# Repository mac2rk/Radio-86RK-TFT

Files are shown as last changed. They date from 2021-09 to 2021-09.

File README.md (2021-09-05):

# Connecting Radio-86RK to TFT display panel

Connecting TFT display with 24bit RGB parallel interface to Intel i8275 CRTC

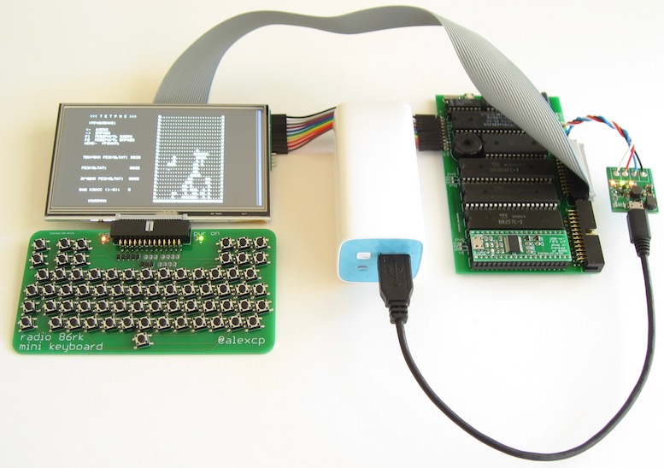
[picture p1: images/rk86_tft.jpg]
Radio-86RK with TFT panel


## Introduction

For many home computers from 1980s, TV was the only display available, and [Radio-86RK](https://github.com/mac2rk/Radio-86RK-SRAM) is no exception. Back then, it made total sense, but today, TVs with composite video input gradualy disappear, and being tethered to one when playing with a 8-bit retro computer is, well, too much retro.

Turns out, small TFT display panels are now available, affordable, and can be connected to Radio-86RK relatively easily.

This project is a hardware interface between Intel i8275 CRT controller and a 480x272 pixel TFT panel [ER-TFT050-2](https://www.buydisplay.com/download/manual/ER-TFT050-2_Datasheet.pdf) with the ILI6482 controller onboard. This inteface board supports 4-bit (IRGB) color, although color is not implemented in [Radio-86RK](https://github.com/mac2rk/Radio-86RK-SRAM). The interface has been shown to work with a Sinclair ZX Spectrum clone (Harlequin), too, although it was not explored in any detail.

## Schematic

[Schematic](Eagle/rk86_tft-schematic.pdf)

In the schematic, IC3 converts logic levels from 5V of [Radio-86RK](https://github.com/mac2rk/Radio-86RK-SRAM) to 3.3V required by the TFT panel; IC6 feeds the TFT panel's backlight (a string of white LEDs) with constant current; IC7 provides I2C interface for the resistive touchscreen; IC8 regulates +5V power supply down to +3.3V. Q1 provides protection against wrong power supply polarity, Q2 and Q3 convert I2C voltage levels.

IC4 and IC5.1 form the brown color `#AA5500`instead of unsightly "dark yellow" `#AAAA00` for IRGB=0b0110, forming the standard CGA palette:

4-bit IRGB code | 24-bit color | Color
--------------- | ------------ | -----
0b0000          | `#000000`    | Black
0b0001          | `#0000AA`    | Blue
0b0010          | `#00AA00`    | Green
0b0011          | `#00AAAA`    | Cyan
0b0100          | `#AA0000`    | Red
0b0101          | `#AA00AA`    | Magenta
0b0110          | `#AA5500`    | Brown
0b0111          | `#AAAAAA`    | Light gray
0b1000          | `#555555`    | Dark gray
0b1001          | `#5555FF`    | Bright blue
0b1010          | `#55FF55`    | Bright green
0b1011          | `#55FFFF`    | Bright cyan
0b1100          | `#FF5555`    | Bright Red
0b1101          | `#FF55FF`    | Bright magenta
0b1110          | `#FFFF55`    | Yellow
0b1111          | `#FFFFFF`    | White

IC2's function is specific to [Radio-86RK](https://github.com/mac2rk/Radio-86RK-SRAM). In Radio-86RK, the i8275 CRTC forms a raster with 300 horizontal lines, although top 30 and bottom 20 are not used for display. The TFT panel, however, is only 272 pixels tall, so 300-20-272=8 lines at the bottom  of the display area do not fit. Thankfully, the TFT panel ignores HRTC pulses and is completely controlled by VRTC and DEN (Data ENable) signals. IC2 suppresses DEN for the top 16 lines, thus fitting the full display area into the panel without reprogramming the CRTC, ensuring compatibility with existing software.

## PCB layout

[PCB layout](Eagle/rk86_tft-board.pdf)

## Bill of Materials

Name              | Part      | Value       | Package | Quantity
----------------- | --------- | ----------- | ------- | --------
LCD1              | LCD panel | ER-TFT050-2 |         | 1
LCD1              | 30-way 0.5mm FPC connector, top contact |  | Molex 54014-4031 | 1
IC1               | Logic IC  | 74HC04PW    | TSSOP14 | 1
IC2               | Logic IC  | 74HC161PW   | TSSOP16 | 1
IC3               | Logic IC  | 74LVC8T245DBQR | TSSOP24 | 1
IC4               | Logic IC  | QS3VH253PAG | TSSOP16 | 1
IC5               | Logic IC  | 74HC08PW    | TSSOP14 | 1
IC6               | Backlight Driver IC | AP3019AKTR | SOT23-6 | 1
IC7               | Touchscreen Controller IC | TSC2007PW | TSSOP16 | 1
IC8               | Voltage Reg IC | MCP1700T-3302E/TT | SOT23-3 | 1
Q1                | Pch MOSFET | FDC658P    | SOT23-6 | 1
Q2,Q3             | Nch MOSFET | BSS138     | SOT23-3 | 2
R1,R2,R4..R7      | Resistor  | 10kOhm | 0805    | 6
R3                | Resistor  | 5ohm   | 0805    | 1
R8..R13           | Resistor  | 220ohm | 0805    | 6
C1..C6, C11, C13  | Capacitor | 0.1uF  | 0805    | 8
C8, C10, C12, C14 | Capacitor | 10uF   | 0805    | 4
C9                | Capacitor | 0.22uF | 0805    | 1
L1                | Inductor | 22uH    | Coilcraft XTL7030 | 1
CLK,DEN,HRTC,I2C,PWR,VRTC | LED |      | 0805    | 6
JP1         | 0.1" Pin Header |        | 1x10    | 1
I2X1        | 0.1" Pin Header |        | 1x4     | 1

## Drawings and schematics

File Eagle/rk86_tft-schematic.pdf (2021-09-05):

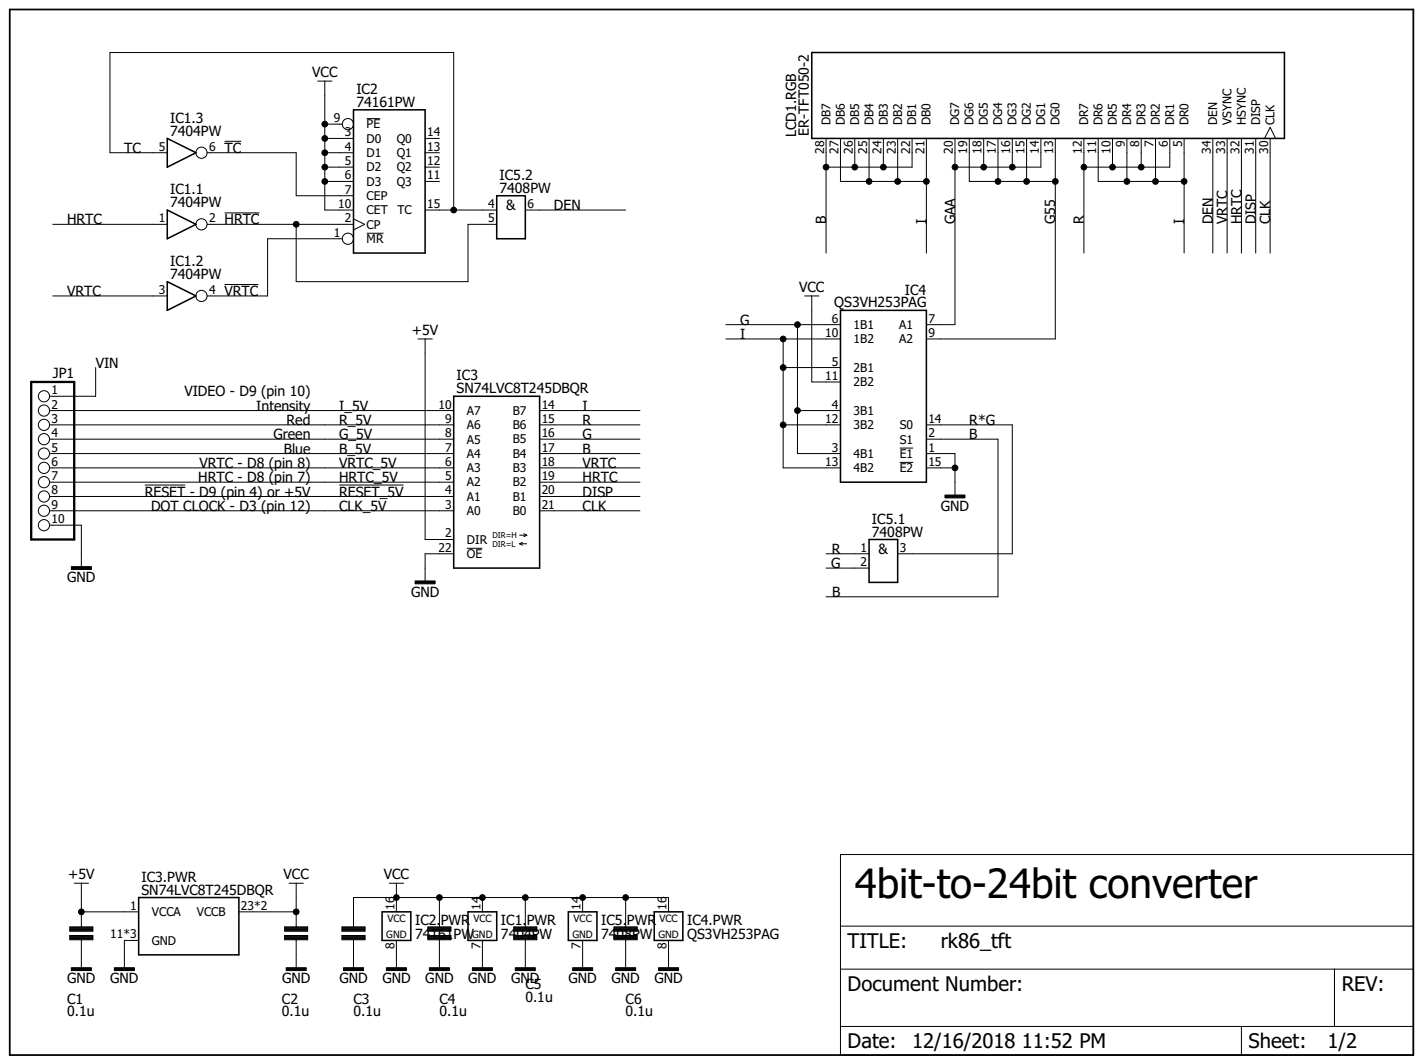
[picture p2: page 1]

VCC

4 | 13
5 | 12
6 | 11
7 | 15

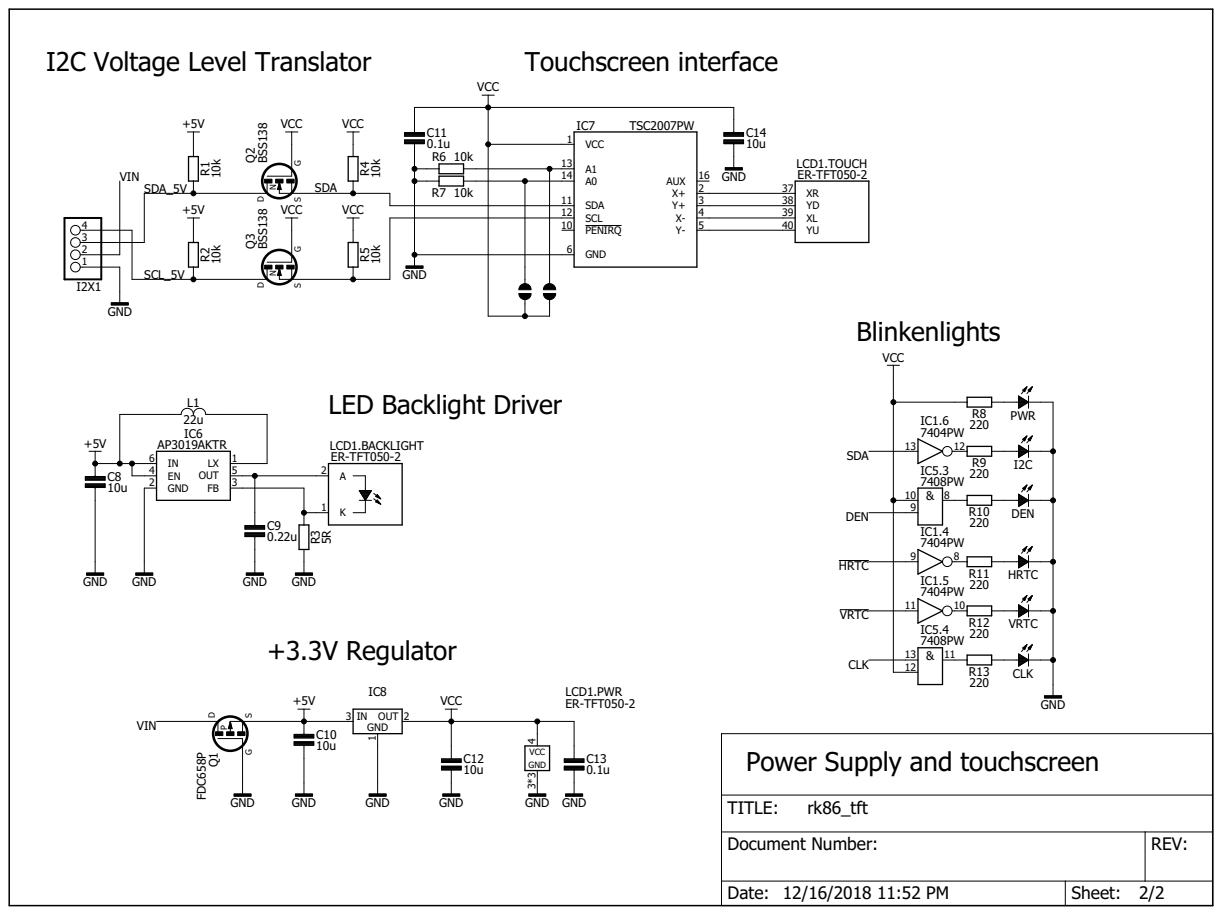
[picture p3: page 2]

VCC GND GND GND

Power Supply and touchscreen

Document Number: | REV:

Date: 12/16/2018 11:52 PM | Sheet: 2/2

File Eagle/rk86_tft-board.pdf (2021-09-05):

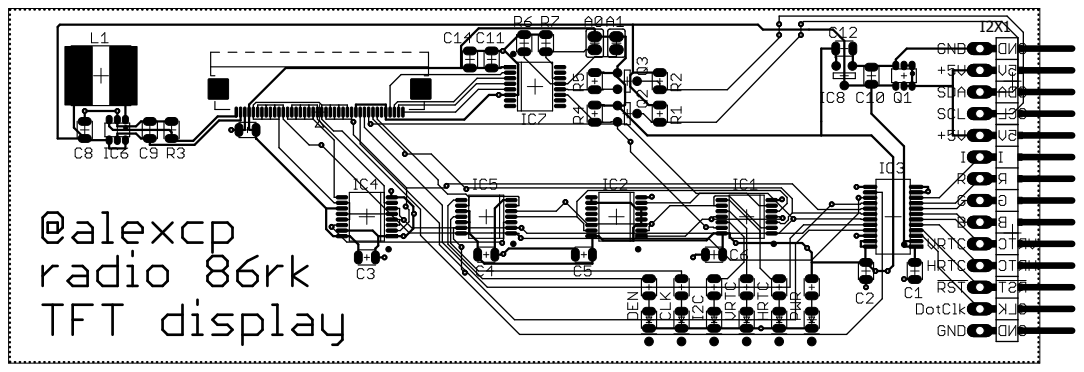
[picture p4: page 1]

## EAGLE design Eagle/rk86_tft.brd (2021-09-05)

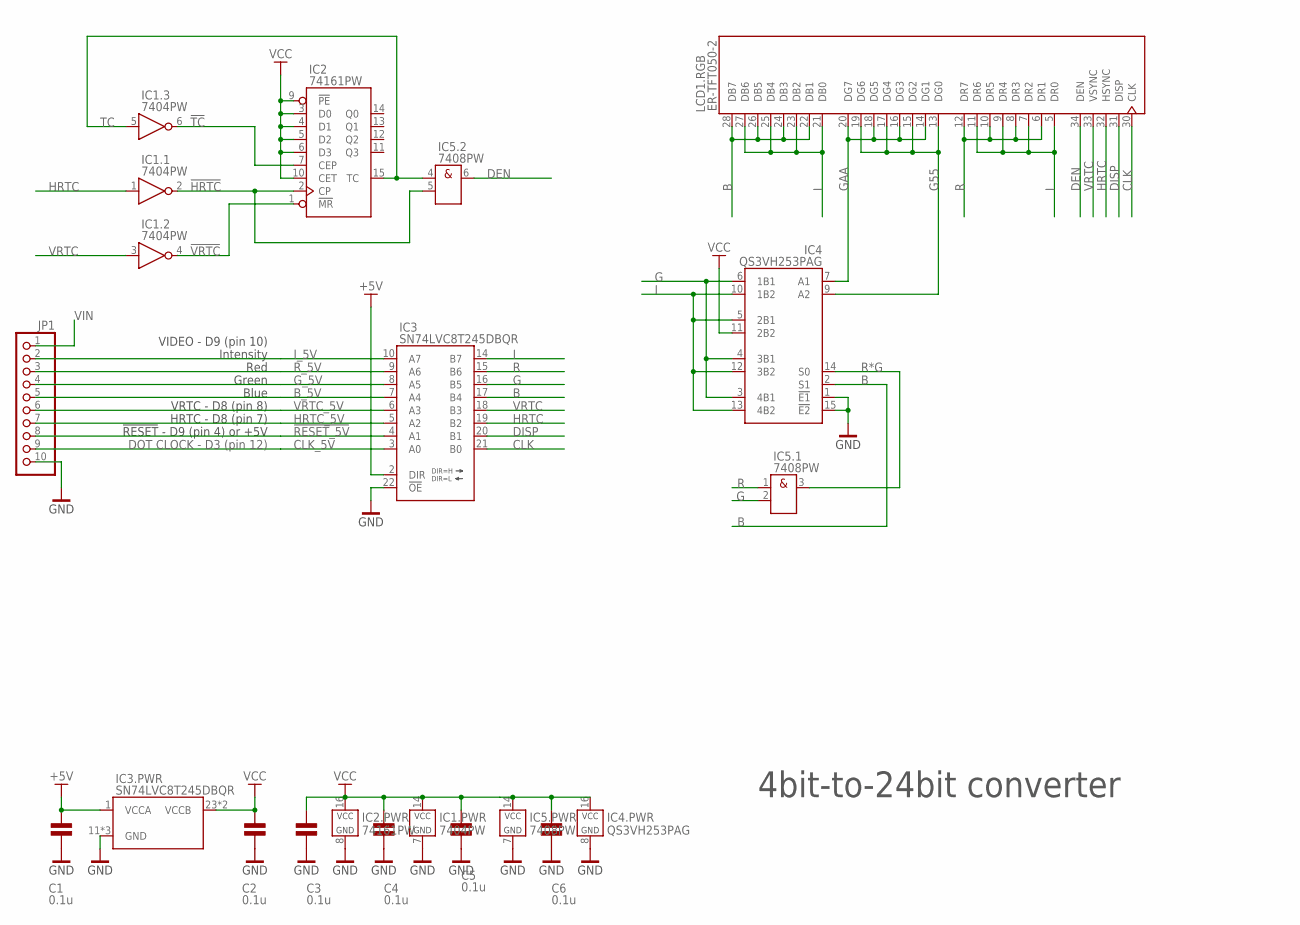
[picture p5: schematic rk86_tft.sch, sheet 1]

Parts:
C1, C2, C3, C4, C5, C6: 0.1u; 0805
IC1: 7404PW; TSSOP14_4.4
IC2: 74161PW; TSSOP16_4.4
IC3: SN74LVC8T245DBQR; TI_DBQ24
IC4: QS3VH253PAG; TSSOP16_4.4
IC5: 7408PW; TSSOP14_4.4
JP1: PINHD-1X10/90; 1X10/90
LCD1: ER-TFT050-2; MOLEX_54104-4031

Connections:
!HRTC: IC1.2 (Y), IC2.2 (CP), IC5.5 (B); also elsewhere on the board
!RESET_5V: IC3.4 (A1), JP1.8
!TC: IC1.6 (Y), IC2.7 (CEP)
!VRTC: IC1.4 (Y), IC2.1 (!MR); also elsewhere on the board
+5V: C1.2, IC3.1 (VCCA), IC3.2 (DIR); also elsewhere on the board
B: IC3.17 (B4), IC4.2 (S1), LCD1.22 (DB1), LCD1.24 (DB3), LCD1.26 (DB5), LCD1.28 (DB7)
B_5V: IC3.7 (A4), JP1.5
CLK: IC3.21 (B0), LCD1.30 (CLK); also elsewhere on the board
CLK_5V: IC3.3 (A0), JP1.9
DEN: IC5.6 (Y), LCD1.34 (DEN); also elsewhere on the board
DISP: IC3.20 (B1), LCD1.31 (DISP)
G: IC3.16 (B5), IC4.3 (4B1), IC4.4 (3B1), IC4.6 (1B1), IC5.2 (B)
G55: IC4.9 (A2), LCD1.13 (DG0), LCD1.15 (DG2), LCD1.17 (DG4), LCD1.19 (DG6)
GAA: IC4.7 (A1), LCD1.14 (DG1), LCD1.16 (DG3), LCD1.18 (DG5), LCD1.20 (DG7)
GND: C1.1, C2.1, C3.1, C4.1, C5.1, C6.1, IC1.7 (GND), IC2.8 (GND), IC3.11 (GND), IC3.12 (GND), IC3.13 (GND), IC3.22 (!OE), IC4.1 (!E1), IC4.8 (GND), IC4.15 (!E2), IC5.7 (GND), JP1.10; also elsewhere on the board
G_5V: IC3.8 (A5), JP1.4
HRTC: IC1.1 (A), IC3.19 (B2), LCD1.32 (HSYNC)
HRTC_5V: IC3.5 (A2), JP1.7
I: IC3.14 (B7), IC4.5 (2B1), IC4.10 (1B2), IC4.12 (3B2), IC4.13 (4B2), LCD1.5 (DR0), LCD1.7 (DR2), LCD1.9 (DR4), LCD1.11 (DR6), LCD1.21 (DB0), LCD1.23 (DB2), LCD1.25 (DB4), LCD1.27 (DB6)
I_5V: IC3.10 (A7), JP1.2
R: IC3.15 (B6), IC5.1 (A), LCD1.6 (DR1), LCD1.8 (DR3), LCD1.10 (DR5), LCD1.12 (DR7)
R*G: IC4.14 (S0), IC5.3 (Y)
R_5V: IC3.9 (A6), JP1.3
TC: IC1.5 (A), IC2.15 (TC), IC5.4 (A)
VCC: C2.2, C3.2, C4.2, C5.2, C6.2, IC1.14 (VCC), IC2.3 (D0), IC2.4 (D1), IC2.5 (D2), IC2.6 (D3), IC2.9 (!PE), IC2.10 (CET), IC2.16 (VCC), IC3.23 (VCCB), IC3.24 (VCCB), IC4.11 (2B2), IC4.16 (VCC), IC5.14 (VCC); also elsewhere on the board
VIN: JP1.1; also elsewhere on the board
VRTC: IC1.3 (A), IC3.18 (B3), LCD1.33 (VSYNC)
VRTC_5V: IC3.6 (A3), JP1.6

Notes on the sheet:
4bit-to-24bit converter
VIDEO - D9 (pin 10)
VRTC - D8 (pin 8)
HRTC - D8 (pin 7)
DOT CLOCK - D3 (pin 12)
!RESET! - D9 (pin 4) or +5V
Intensity
Red
Green
Blue

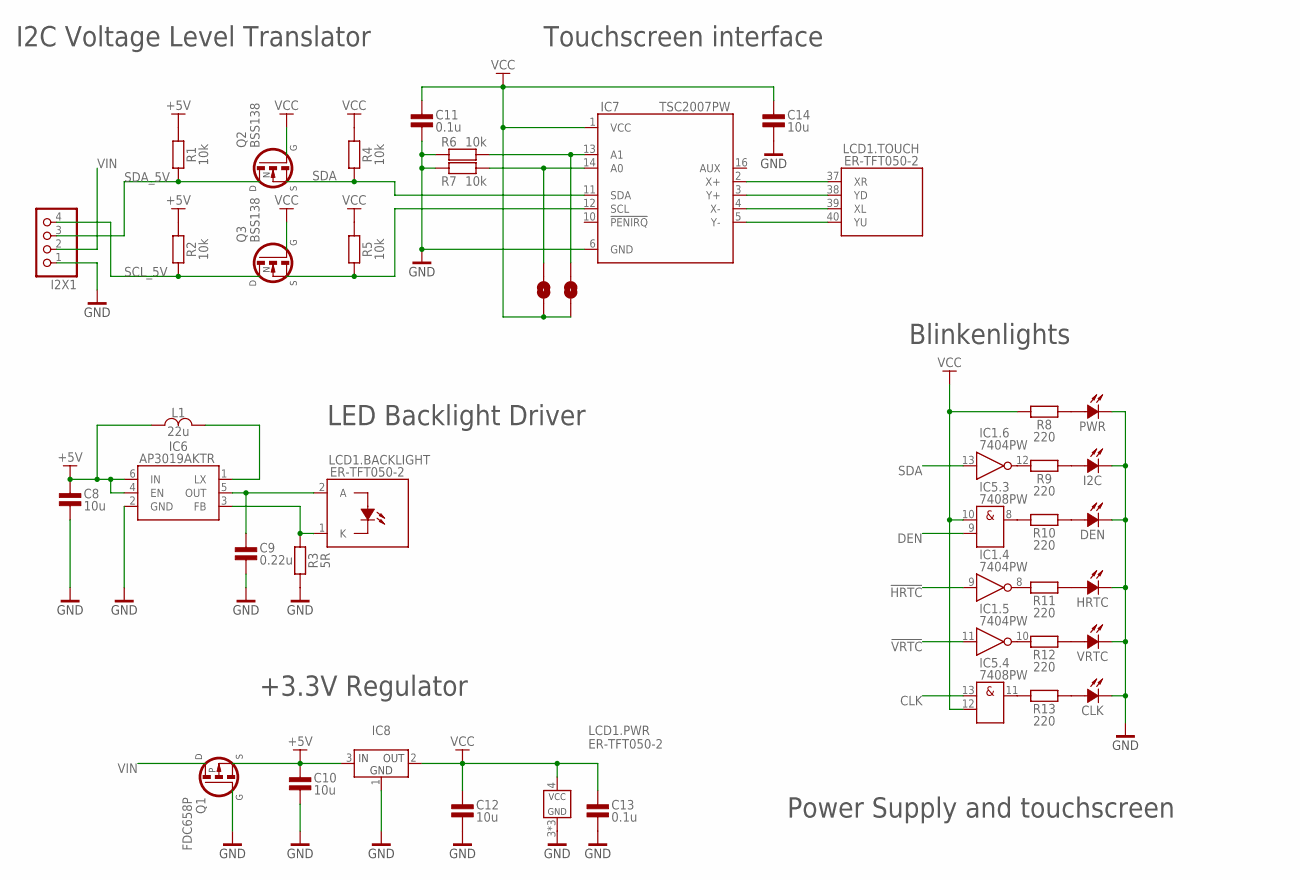
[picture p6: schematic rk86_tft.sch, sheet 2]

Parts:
A0, A1: SJ
C8, C10, C12, C14: 10u; 0805
C9: 0.22u; 0805
C11, C13: 0.1u; 0805
CLK: LED0805; 0805POL
DEN: LED0805; 0805POL
HRTC: LED0805; 0805POL
I2C: LED0805; 0805POL
I2X1: PINHD-1X4/90; 1X04/90
IC1: 7404PW; TSSOP14_4.4
IC5: 7408PW; TSSOP14_4.4
IC6: AP3019AKTR; SOT23-6
IC7: TSC2007PW; TSSOP16_4.4
IC8: MCP1700TT; SOT23-3
L1: 22u; COILCRAFT_XTL7030
LCD1: ER-TFT050-2; MOLEX_54104-4031
PWR: LED0805; 0805POL
Q1: FDC658P; SOT23-6
Q2, Q3: BSS138; SOT23-3
R1, R2, R4, R5, R6, R7: 10k; 0805
R3: 5R; 0805
R8, R9, R10, R11, R12, R13: 220; 0805
VRTC: LED0805; 0805POL

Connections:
!HRTC: IC1.9 (A); also elsewhere on the board
!VRTC: IC1.11 (A); also elsewhere on the board
+5V: C8.2, C10.2, IC6.4 (EN), IC6.6 (IN), IC8.3 (IN), L1.1, Q1.4 (S), R1.2, R2.2; also elsewhere on the board
CLK: IC5.13 (A); also elsewhere on the board
DEN: IC5.9 (B); also elsewhere on the board
GND: C8.1, C9.1, C10.1, C11.1, C12.1, C13.1, C14.1, CLK.K, DEN.K, HRTC.K, I2C.K, I2X1.1, IC6.2 (GND), IC7.6 (GND), IC8.1 (GND), LCD1.3 (GND), LCD1.29 (GND), LCD1.36 (GND), PWR.K, Q1.3 (G), R3.1, R6.1, R7.1, VRTC.K; also elsewhere on the board
LEDA: C9.2, IC6.5 (OUT), LCD1.2 (A)
LEDK: IC6.3 (FB), LCD1.1 (K), R3.2
LX: IC6.1 (LX), L1.2
unnamed: IC1.8 (Y), R11.1
unnamed: IC1.10 (Y), R12.1
unnamed: IC1.12 (Y), R9.1
unnamed: IC5.11 (Y), R13.1
unnamed: IC5.8 (Y), R10.1
unnamed: A1.2, IC7.13 (A1), R6.2
unnamed: A0.2, IC7.14 (A0), R7.2
unnamed: I2C.A, R9.2
unnamed: DEN.A, R10.2
unnamed: HRTC.A, R11.2
unnamed: R12.2, VRTC.A
unnamed: IC7.2 (X+), LCD1.37 (XR)
unnamed: IC7.4 (X-), LCD1.39 (XL)
unnamed: IC7.3 (Y+), LCD1.38 (YD)
unnamed: IC7.5 (Y-), LCD1.40 (YU)
unnamed: CLK.A, R13.2
unnamed: PWR.A, R8.2
SCL: IC7.12 (SCL), Q3.2 (S), R5.1
SCL_5V: I2X1.4, Q3.3 (D), R2.1
SDA: IC1.13 (A), IC7.11 (SDA), Q2.2 (S), R4.1
SDA_5V: I2X1.3, Q2.3 (D), R1.1
VCC: A0.1, A1.1, C11.2, C12.2, C13.2, C14.2, IC5.10 (A), IC5.12 (B), IC7.1 (VCC), IC8.2 (OUT), LCD1.4 (VCC), Q2.1 (G), Q3.1 (G), R4.2, R5.2, R8.1; also elsewhere on the board
VIN: I2X1.2, Q1.1 (D), Q1.2 (D), Q1.5 (D), Q1.6 (D); also elsewhere on the board

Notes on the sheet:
I2C Voltage Level Translator
+3.3V Regulator
LED Backlight Driver
Touchscreen interface
Blinkenlights
Power Supply and touchscreen

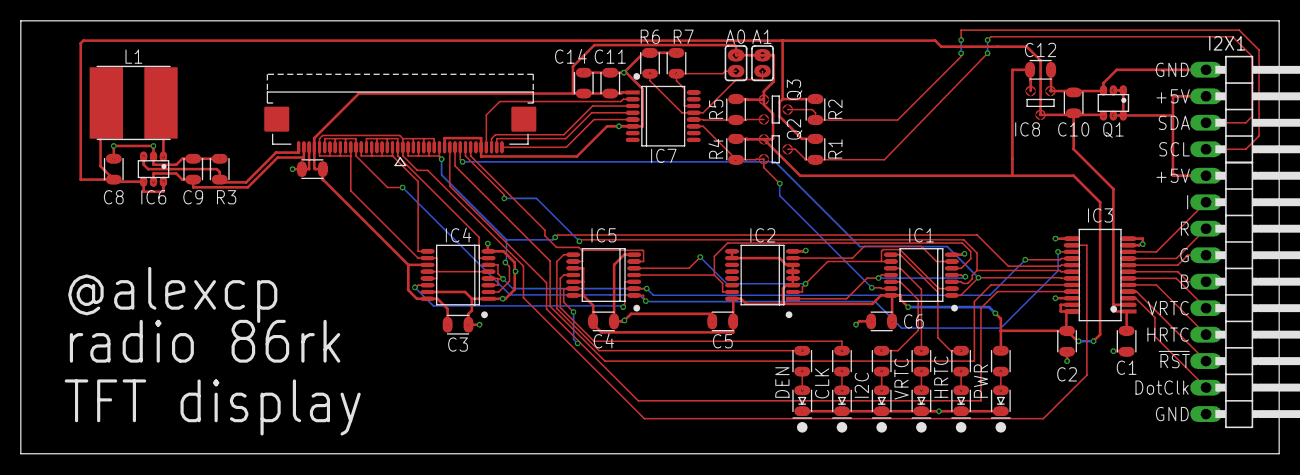
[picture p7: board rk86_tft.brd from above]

Board: 2 copper layers, 120.7 x 41.5 mm, 49 parts (0 on the bottom side), 52 nets.
